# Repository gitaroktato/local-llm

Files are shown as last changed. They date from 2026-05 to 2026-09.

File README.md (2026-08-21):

# Local LLM 
A combination of hardware and software capable of running LLMs for coding locally. 

## Execution Environments

- [Arch Linux and Unsloth](./arch-linux-unsloth.md)
- [Windows WSL with vLLM](./windows-wsl-vllm.md)
- 
## Hardware

Full bill of materials (BOM), PCIe topology, riser cables and 3D-printed parts: [hardware-bom.md](./hardware-bom.md)

- CPU: Intel Core i5-14400F · MB: ASUS ROG MAXIMUS Z690 HERO
- GPU: 2× NVIDIA RTX 5060 Ti 16GB (Gen5 x16 + Gen5 x1 riser path)
- RAM: 32GB DDR5-5200 (Kingston FURY Beast) · PSU: ASUS ROG STRIX 1000G

## Images
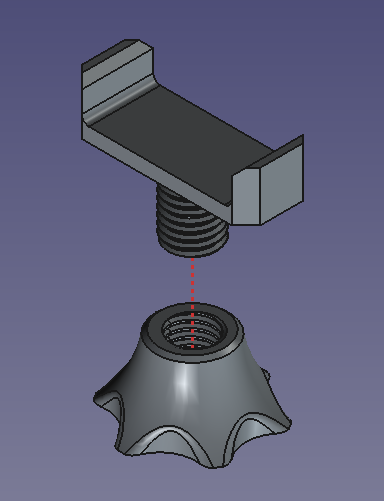
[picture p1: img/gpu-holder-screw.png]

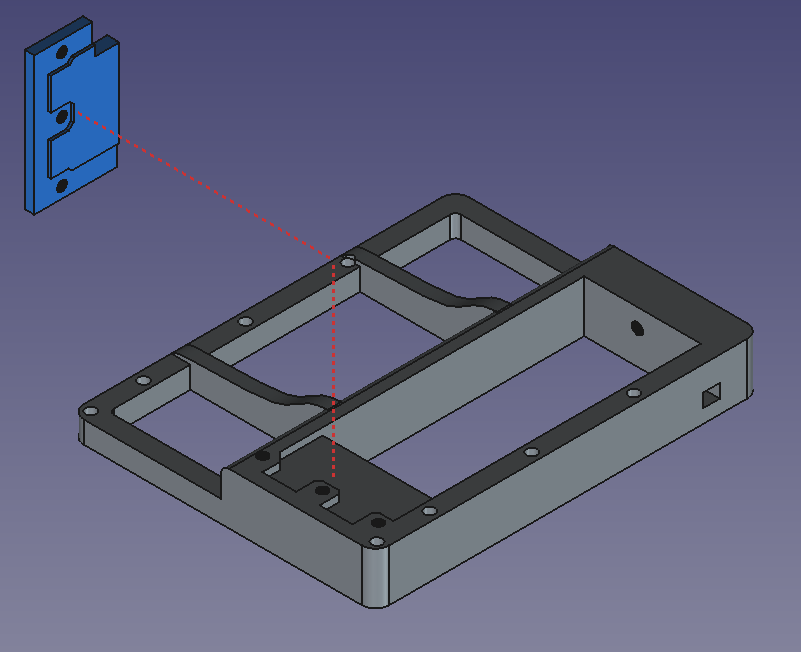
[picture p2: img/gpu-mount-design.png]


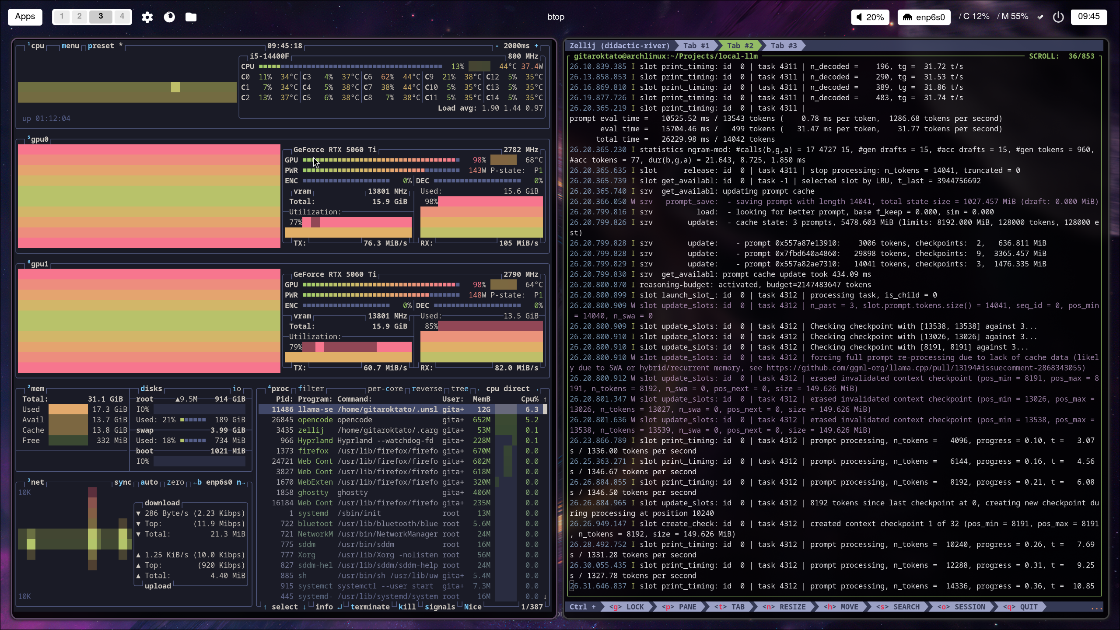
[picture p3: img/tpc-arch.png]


## Tools

Setting CPU governance

```bash
sudo cpupower frequency-set -g performance
```

- [GPU power cap ("undervolt")](./gpu-undervolt.md)

## References

- <https://zread.ai/abetlen/llama-cpp-python/20-kv-cache-strategies>
- <https://github.com/ggml-org/llama.cpp/discussions/14758>

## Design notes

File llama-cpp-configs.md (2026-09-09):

# llama-cpp Configs

Tip: Add `--metrics` for metrics

## Qwen 3.6 Q4_XL with 128k context window using Q5_1

```bash
llama-server -m /home/gitaroktato/.cache/huggingface/hub/models--unsloth--Qwen3.6-27B-GGUF/snapshots/82d411acf4a06cfb8d9b073a5211bf410bfc29bf/Qwen3.6-27B-UD-Q4_K_XL.gguf --port 35019 -c 128000 --parallel 1 --flash-attn on --no-context-shift -ngl -1 --threads -1 --jinja --cache-type-k q5_1 --cache-type-v q5_1 --spec-default --chat-template-kwargs {"enable_thinking": true} --mmproj /home/gitaroktato/.cache/huggingface/hub/models--unsloth--Qwen3.6-27B-GGUF/snapshots/82d411acf4a06cfb8d9b073a5211bf410bfc29bf/mmproj-F16.gguf
```

### Split-mode - tensor (simple run)

```bash
llama-server -m /home/gitaroktato/.cache/huggingface/hub/models--unsloth--Qwen3.6-27B-GGUF/snapshots/82d411acf4a06cfb8d9b073a5211bf410bfc29bf/Qwen3.6-27B-UD-Q4_K_XL.gguf --metrics --port 8888 -c 128000 --parallel 1 --flash-attn on --no-context-shift -ngl -1 --threads 16 --split-mode tensor --fit off --jinja --cache-type-k bf16 --cache-type-v bf16 --spec-default --chat-template-kwargs '{"enable_thinking": true}' --mmproj /home/gitaroktato/.cache/huggingface/hub/models--unsloth--Qwen3.6-27B-GGUF/snapshots/82d411acf4a06cfb8d9b073a5211bf410bfc29bf/mmproj-F16.gguf
```

## Qwen 3.6 35B-A3B Q4_XL with 128k context window

```bash
llama-server -m /home/gitaroktato/.cache/huggingface/hub/models--unsloth--Qwen3.6-35B-A3B-GGUF/snapshots/a483e9e6cbd595906af30beda3187c2663a1118c/Qwen3.6-35B-A3B-UD-Q4_K_XL.gguf --port 48713 -c 262144 --parallel 1 --flash-attn on --no-context-shift -ngl -1 --threads -1 --jinja --spec-default --chat-template-kwargs {"enable_thinking": false} --mmproj /home/gitaroktato/.cache/huggingface/hub/models--unsloth--Qwen3.6-35B-A3B-GGUF/snapshots/a483e9e6cbd595906af30beda3187c2663a1118c/mmproj-F16.gguf
```

### Split-mode - tensor (simple run)

```bash
llama-server -m /home/gitaroktato/.cache/huggingface/hub/models--unsloth--Qwen3.6-35B-A3B-GGUF/snapshots/a483e9e6cbd595906af30beda3187c2663a1118c/Qwen3.6-35B-A3B-UD-Q4_K_XL.gguf  --port 8888 -c 128000 --parallel 1 --flash-attn on --no-context-shift -ngl -1 --threads 16 --split-mode tensor --fit off --jinja --cache-type-k bf16 --cache-type-v bf16 --spec-default --chat-template-kwargs '{"enable_thinking": true}' --mmproj  /home/gitaroktato/.cache/huggingface/hub/models--unsloth--Qwen3.6-35B-A3B-GGUF/snapshots/a483e9e6cbd595906af30beda3187c2663a1118c/mmproj-F16.gguf
```

## Qwen 3.8 - split-mode tensor (simple run)

```bash
llama-server -m /home/gitaroktato/.cache/huggingface/hub/models--unsloth--Qwen3.8-27B-GGUF/snapshots/f1bfb127c64f7072bdd2cad55f258b9c8b2910fe/Qwen3.8-27B-UD-Q5_K_XL.gguf --port 8888 --parallel 4 --flash-attn on --no-context-shift -c 128000 --alias unsloth/Qwen3.8-27B-GGUF -ngl -1 --threads 16 --split-mode tensor --fit off --metrics --slot-save-path /home/gitaroktato/.unsloth/studio/cache/llama-slots --cache-type-k bf16 --cache-type-v bf16 --kv-unified --jinja --spec-type ngram-mod --spec-ngram-mod-n-match 24 --spec-ngram-mod-n-min 48 --spec-ngram-mod-n-max 64 --chat-template-kwargs '{"enable_thinking": true, "preserve_thinking": false, "reasoning_effort":"medium"}' --mmproj /home/gitaroktato/.cache/huggingface/hub/models--unsloth--Qwen3.8-27B-GGUF/snapshots/f1bfb127c64f7072bdd2cad55f258b9c8b2910fe/mmproj-F16.gguf
```

From `unsloth studio`

```bash
llama-server -m /home/gitaroktato/.cache/huggingface/hub/models--unsloth--Qwen3.8-27B-GGUF/snapshots/f1bfb127c64f7072bdd2cad55f258b9c8b2910fe/Qwen3.8-27B-UD-Q5_K_XL.gguf --port 37741 --parallel 1 --flash-attn on --no-context-shift -c 104448 --alias unsloth/Qwen3.8-27B-GGUF -ngl -1 --fit off --metrics --slot-save-path /home/gitaroktato/.unsloth/studio/cache/llama-slots --jinja --split-mode tensor --spec-type draft-mtp --spec-draft-n-max 2 --chat-template-kwargs {"enable_thinking": true, "preserve_thinking": true} --mmproj /home/gitaroktato/.cache/huggingface/hub/models--unsloth--Qwen3.8-27B-GGUF/blobs/cbb841a9ee0636b2ec172f5bb8df2ea8dfeb01e90fe7c6126581d662a0b4e43e
```

```bash
llama-server -m /home/gitaroktato/.cache/huggingface/hub/models--unsloth--Qwen3.8-27B-GGUF/snapshots/f1bfb127c64f7072bdd2cad55f258b9c8b2910fe/Qwen3.8-27B-UD-Q5_K_XL.gguf --port 43775 --parallel 1 --flash-attn on --no-context-shift -c 101632 --alias unsloth/Qwen3.8-27B-GGUF -ngl -1 --fit off --metrics --slot-save-path /home/gitaroktato/.unsloth/studio/cache/llama-slots --jinja --split-mode tensor --spec-type draft-mtp --spec-draft-n-max 2 --chat-template-kwargs {"enable_thinking": true, "preserve_thinking": true} --mmproj /home/gitaroktato/.cache/huggingface/hub/models--unsloth--Qwen3.8-27B-GGUF/blobs/cbb841a9ee0636b2ec172f5bb8df2ea8dfeb01e90fe7c6126581d662a0b4e43e --threads 16
```

Optimization run 3

```bash
llama-server -m /home/gitaroktato/.cache/huggingface/hub/models--unsloth--Qwen3.8-27B-GGUF/snapshots/f1bfb127c64f7072bdd2cad55f258b9c8b2910fe/Qwen3.8-27B-UD-Q5_K_XL.gguf --port 41207 --parallel 1 --flash-attn on --no-context-shift -c 79616 --ubatch-size 1024 --alias unsloth/Qwen3.8-27B-GGUF -ngl -1 --fit off --metrics --slot-save-path /home/gitaroktato/.unsloth/studio/cache/llama-slots --jinja --split-mode tensor --spec-type draft-mtp --spec-draft-n-max 2 --chat-template-kwargs {"enable_thinking": true, "preserve_thinking": true} --mmproj /home/gitaroktato/.cache/huggingface/hub/models--unsloth--Qwen3.8-27B-GGUF/blobs/cbb841a9ee0636b2ec172f5bb8df2ea8dfeb01e90fe7c6126581d662a0b4e43e --threads 10
```

Optimization run 4 (vision on CPU) - not good, eats a lot of CPU

```bash
llama-server -m /home/gitaroktato/.cache/huggingface/hub/models--unsloth--Qwen3.8-27B-GGUF/snapshots/f1bfb127c64f7072bdd2cad55f258b9c8b2910fe/Qwen3.8-27B-UD-Q5_K_XL.gguf --port 48705 --parallel 1 --flash-attn on --no-context-shift -c 128000 --ubatch-size 1024 --alias unsloth/Qwen3.8-27B-GGUF --fit on --metrics --slot-save-path /home/gitaroktato/.unsloth/studio/cache/llama-slots --fit-ctx 128000 --fit-target 547 --jinja --spec-type none --chat-template-kwargs {"enable_thinking": true, "preserve_thinking": true} --mmproj /home/gitaroktato/.cache/huggingface/hub/models--unsloth--Qwen3.8-27B-GGUF/blobs/cbb841a9ee0636b2ec172f5bb8df2ea8dfeb01e90fe7c6126581d662a0b4e43e --threads 10 --split-mode layer --no-mmproj-offload
```

## Interesting things to try

- <https://www.reddit.com/r/LocalLLM/comments/1was9n0/running_qwen_38_27b_at_q4_on_16gb_vram_at_200k/>

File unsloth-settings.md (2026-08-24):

# Unsloth settings through UI

- KV cache: f16
- Speculative decoding: auto
- Parallel slots: 1
- Batch size: auto
- Micro-batch size: 1024
- Tensor parallelism: true
- Vision: true
- GPU memory: default
- VRAM budget: 98%
- GPUs: all on
- Chat Template: default
- Mmap / Mlock: auto
- Checkpoints: auto
- Cache RAM: auto

Additional args

```bash
--threads 10 --chat-template-file /home/gitaroktato/Projects/local-llm/chat-templates/qwen3.8-froggeric-v22.3.jinja --reasoning-format deepseek
```

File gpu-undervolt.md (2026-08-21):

# GPU Power Cap ("Undervolt")

On NVIDIA Linux there is no true mV undervolt — the closest equivalent is a **power-limit cap** via `nvidia-smi -pl`. This page documents why, how it was applied on this machine (2× RTX 5060 Ti, driver `610.57.04`), and how to keep it across reboots.

## Why not a real undervolt?

- NVIDIA has never exposed a voltage-offset API in NVML on Linux. Probing `libnvidia-ml.so` confirms: no voltage-related symbols exist.
- mV undervolting (MSI Afterburner / Rivatuner) is **Windows-only**.
- Clock locking (`nvidia-smi -lgc`) is deprecated for this Blackwell driver generation — P-state query APIs return `NOT_SUPPORTED`, and nvidia-smi marks Applications Clocks as "deprecated". Excluded from scope.

The power cap is a soft PMU constraint: fully reversible, zero hardware risk. For LLM inference (often memory-bandwidth-bound and rarely at TDP), dropping the limit typically costs only a few % of throughput while cutting heat, noise and wall power.

## Applying the cap

Allowed range per card on the RTX 5060 Ti: **150–180 W** (stock `180 W`).

```bash
# check current limits
nvidia-smi --query-gpu=index,power.limit,power.default_limit,power.min_limit,power.max_limit --format=csv

# apply 150 W to all GPUs (applies live, no restart needed; root required)
sudo nvidia-smi -pl 150

# verify
nvidia-smi --query-gpu=index,power.limit --format=csv
```

Note: plain `-pl <watts>` already targets all GPUs. Do not use `--gpu-all` (not recognized) or `-i ALL` ("No devices found") on driver `610.x` — both fail. Setting the limit requires root; querying does not.

This machine runs at **150 W** on both GPUs. The cap was chosen directly (no 180/165/150 W perf-loss table was recorded) — inference throughput was acceptable and heat/noise reduction was the goal.

## Persistence across reboots

The cap does not survive a driver reload or reboot by itself. Two pieces:

### 1. `nvidia-persistenced`

Keeps the driver loaded (and the daemon context alive) between sessions:

```bash
sudo systemctl enable --now nvidia-persistenced
```

### 2. Oneshot unit applying the cap at boot

`/etc/systemd/system/gpu-power-cap.service`:

```ini
[Unit]
Description=Apply 150 W power cap to all NVIDIA GPUs
After=sysinit.target nvidia-persistenced.service
ConditionPathExists=/usr/bin/nvidia-smi

[Service]
Type=oneshot
RemainAfterExit=yes
ExecStart=/bin/sh -c 'for i in $(seq 1 30); do nvidia-smi -pl 150 >/dev/null && exit 0; sleep 2; done; echo "gpu-power-cap: failed to apply power limit after retries" >&2; exit 1'

[Install]
WantedBy=multi-user.target
```

The retry loop (30 × 2 s) covers the case where the nvidia module is not up yet when the unit runs. Install and enable:

```bash
sudo cp gpu-power-cap.service /etc/systemd/system/
sudo systemctl daemon-reload
sudo systemctl enable --now gpu-power-cap.service
```

### Verify after reboot

```bash
nvidia-smi --query-gpu=index,power.limit --format=csv   # expect 150.00 W on both
systemctl status gpu-power-cap.service nvidia-persistenced.service
```

## Revert

```bash
sudo nvidia-smi -pl 180              # restore stock limit on all GPUs (live)
sudo systemctl disable --now gpu-power-cap.service   # optional: stop forcing the cap at boot
```

No clock locks, no register hacks — everything is reversible.

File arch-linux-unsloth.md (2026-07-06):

# Running through Unsloth + Arch Linux

## Commands

### PCIe testing

Getting PCIe lane bandwidth (possible):

```shell
sudo watch -c -n2 'lspci -s 00:01.0 -vvv | grep LnkSta'
```

Understanding actual bandwidth with `nvidia-smi`:

```shell
nvidia-smi dmon -s pceutv -d 1
```

Just RX/TX

```shell
nvidia-smi dmon -s t -d 1
```

### PCIe benchmarks

Stress-testing PCIe port
Should be possible with `gpu-burn-git`: <https://aur.archlinux.org/packages/gpu-burn-git>

### Using `nvbandwith`

See: https//github.com/NVIDIA/nvbandwidth

Make sure you have NVidia toolkit and `nvcc` installed.
Put the following lines into your `.bashrc`

```bash
export PATH=/opt/cuda/bin:$PATH
export LD_LIBRARY_PATH=/opt/cuda/lib64:$LD_LIBRARY_PATH
```

Add `boost-libs` with

```shell
sudo pacman -S boost boost-libs
```

Compile from source with

```bash
cmake .
make
```

Run benchmarks:

```bash
nvbandwidth -t host_to_device_bidirectional_memcpy_ce
nvbandwidth -t device_to_host_bidirectional_memcpy_ce
nvbandwidth -t host_to_device_bidirectional_memcpy_sm
nvbandwidth -t device_to_host_bidirectional_memcpy_sm
nvbandwidth -p device_to_host_bidirectional -i 16
nvbandwidth -p host_to_device_bidirectional -i 16
```

Reference numbers:

| PCIe generation | Signaling rate (GT/s per lane) | Encoding | Effective per-lane throughput (GB/s) | Effective x4 link, one-way (GB/s) | Effective x8 link, one-way (GB/s) |
|---|---:|---|---:|---:|---:|
| PCIe 3.0 | 8.0 | 128b/130b | 0.985 | 3.94 | 7.88 |
| PCIe 4.0 | 16.0 | 128b/130b | 1.969 | 7.88 | 15.75 |
| PCIe 5.0 | 32.0 | 128b/130b | 3.938 | 15.75 | 31.51 |

Notes:

- Values are unidirectional (one-way) effective line rates accounting for 128b/130b encoding overhead only. Additional PCIe protocol overhead further reduces payload throughput.
- PCIe links are full-duplex; the reverse direction has the same capacity.

## Target Hardware

- OS: Arch Linux
- GPU: RTX 5060 Ti 16GB
- Runtime: Unsloth + llama.cpp

## Possible Performance Bottlenecks

<!-- TODO local model bottlenecks VRAM throughput?? -->

## Optimizations per Task

### Qwen3.6-35B-A3B-GGUF

<!-- TODO local model optimizations and correct settings -->

<https://unsloth.ai/docs/models/qwen3.6#turn-on-off-thinking--preserve-thinking>

## Configuration and Optimization Tips

### 🧠 Memory & Quantization

- **Quantize model weights** — Reduce 16-bit weights to 8-bit or 4-bit using Unsloth's GGUF export
  to cut VRAM usage. The performance drop from 16→8 bit is far smaller than from 8→4 bit, so prefer
  Q8 where VRAM allows and fall back to Q4 when needed.
- **Prefer larger models with aggressive quantization over smaller precise ones** — A Q4 30B model
  generally outperforms a full-precision 7B model for coding tasks.
- **Be cautious with KV cache quantization** — `llama.cpp` supports KV cache quantization via
  `-ctk` / `-ctv` flags (e.g., `q8_0`). This is considered *more destructive* than weight
  quantization because it causes the model to lose detail in long reasoning traces. Benchmark your
  specific task before enabling it.
- **Prioritize a precise KV cache for coding/reasoning** — For agentic coding sessions where long
  context matters, keep KV cache at `f16` or `q8_0` and instead shrink the model size to fit VRAM.
  See related paper: <https://arxiv.org/pdf/2510.10964>
- **Monitor actual VRAM usage** — Use `nvidia-smi` (NVIDIA) or `rocm-smi` (AMD) to confirm the
  model fits in VRAM. Spilling into system RAM via llama.cpp's `-ngl` GPU offloading will
  drastically reduce tokens/second.

### 🏗️ Model Architecture & Selection

- **Prefer Hybrid Attention architectures** — Models like Qwen3 with Hybrid Attention have a
  significantly smaller KV cache footprint, letting you run a larger model within the same VRAM
  budget.
- **Use Instruct models for chat-based coding tools** — Use instruct-tuned variants (e.g.,
  `Qwen3-Coder-*-Instruct`) with tools like OpenCode or Continue. Use base models only for
  fill-in-the-middle (FIM) autocomplete.

### ⚡ llama.cpp Runtime Tuning

- **Maximize GPU layer offloading** — Pass `-ngl 99` (or the maximum layer count of your model) to
  offload all layers to the GPU. Partial offloading (`-ngl <n>`) is a valid fallback when VRAM is
  tight, at the cost of speed.
- **Set an appropriate context size** — Use `-c 65536` or larger for coding sessions. Prefer models
  with Hybrid Attention to keep the KV cache cost of a large context manageable.
- **Tune batch and thread counts** — Use `-b 512` or `-b 1024` to balance prompt processing
  throughput. Set `-t` to the number of physical CPU cores for CPU-assisted layers.
- **Watch time-to-first-token and tokens/second** — Both matter for interactive coding. If
  tokens/second is too low, reduce context size, increase quantization, or reduce `-ngl` to leave
  more VRAM headroom for the KV cache.

### 📐 Model Size Reference (VRAM Requirements — GGUF Q4)

| Model | Approx. VRAM |
|---|---|
| Qwen3-4B-Instruct Q4 | ~3 GB |
| Qwen2.5-14B-Instruct Q4 | ~9 GB |
| Qwen3-Coder-30B-A3B-Instruct Q4 | ~18 GB |
| Qwen3-Coder-30B-A3B-Instruct Q8 | ~33 GB |
| Qwen3-Next-80B-A3B-Instruct Q4 | ~48 GB |

Use the [VRAM calculator](https://apxml.com/tools/vram-calculator) for precise estimates including
KV cache overhead for your target context length.

### 📝 Usage & Workflow

- **Manage context deliberately** — Only include files and context directly relevant to the current
  task. Bloated context degrades performance and increases KV cache memory pressure.
- **Use OpenAI-compatible tools** — Tools that speak the OpenAI API standard (OpenCode, Continue,
  Aider, Roo Code) make it trivial to swap models without reconfiguring the tool.

## Bookmarks

### Hardware

- [PCIe Accelerator - Skymizer HTX301](https://wccftech.com/this-pcie-ai-accelerator-card-packs-384-gb-memory-run-700b-llms-240w/)
- [Blackhole PCIe](https://tenstorrent.com/hardware/cards)

### Embedded

- [RPi AI HAT +2](https://www.raspberrypi.com/documentation/accessories/ai-hat-plus.html#AIHAT-models)
- [RPi + M.2 via OCuLink](https://youtu.be/SPTYjF8qH0A)
- [RPi + M.2 via OCuLink #2](https://youtu.be/b58eok9TP9Y)
- [RPi + M.2 via OCuLink #3](https://youtu.be/jeuOMDfY-MI)
- [RPi + M.2 via OCuLink #4](https://youtu.be/AyR7iCS7gNI)

### Hardware Builds

- [Personal-AI-Computer](https://github.com/autonomous-ai/Personal-AI-Computer/tree/main)
- [Personal AI Computerhttps://github.com/autonomous-ai/Personal-AI-Computer/tree/main#bios-optimization-for-gpu-performance Blog](https://www.autonomous.ai/ourblog/how-to-build-your-own-personal-ai-computer)

### Benchmarks

- [Choosing right GPU for LLMs](https://www.llamabuilds.ai/blog/choosing-right-gpu-for-llms)
- [LLM Benchmarks](https://www.llamabuilds.ai/benchmarks)
- [swe-bench-verified](https://llm-stats.com/benchmarks/swe-bench-verified)
- [livecodebench](https://llm-stats.com/benchmarks/livecodebench)

### Tools

- [pi.dev](https://pi.dev/docs/latest)

### Useful Links

- [VRAM calculator](https://apxml.com/tools/vram-calculator)
- [Unsloth with OpenCode](https://unsloth.ai/docs/integrations/opencode)
- [Guide on local LLMs](https://www.reddit.com/r/LocalLLaMA/comments/1sknx6n/best_local_llms_apr_2026/)

### Blogposts

- [Local LLM introduction](https://www.aiforswes.com/p/you-dont-need-to-spend-100mo-on-claude)

### Benchmarking

- <https://openbenchmarking.org/>

### Papers

- [Context window VS model quantization](https://arxiv.org/pdf/2510.10964)
- [Qwen3 training and inference optimizations](https://qwen.ai/blog?id=4074cca80393150c248e508aa62983f9cb7d27cd&from=research.latest-advancements-list)

### Qwen model configs

- <https://docsmith.aigne.io/docs/qwen-agent/en/reference-models-d8daab#example%3A-efficient-configuration>

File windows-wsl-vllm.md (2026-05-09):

# Local LLM with vLLM

## Installing CUDA drivers on WSL 

### Installing CUDA drivers

```shell
wget https://developer.download.nvidia.com/compute/cuda/repos/wsl-ubuntu/x86_64/cuda-keyring_1.1-1_all.deb
sudo dpkg -i cuda-keyring_1.1-1_all.deb
sudo apt-get update
sudo apt-get -y install cuda-toolkit-13-1
```

### Verifying CUDA drivers

Verify CUDA version on the right side.

```shell
nvidia-smi
```

### Install Docker

Download and install docker

```shell
curl https://get.docker.com | sh
sudo service docker start
```

Allow docker for non-root users as well

```shell
sudo groupadd docker
sudo usermod -aG docker $USER
newgrp docker
```

### Install CUDA Container Toolkit

Install the prerequisites for the instructions below
```shell
sudo apt-get update && sudo apt-get install -y --no-install-recommends \
   curl \
   gnupg2
```

Configure the production repository

```shell
curl -fsSL https://nvidia.github.io/libnvidia-container/gpgkey | sudo gpg --dearmor -o /usr/share/keyrings/nvidia-container-toolkit-keyring.gpg \
  && curl -s -L https://nvidia.github.io/libnvidia-container/stable/deb/nvidia-container-toolkit.list | \
    sed 's#deb https://#deb [signed-by=/usr/share/keyrings/nvidia-container-toolkit-keyring.gpg] https://#g' | \
    sudo tee /etc/apt/sources.list.d/nvidia-container-toolkit.list
```

Update the packages list from the repository
```shell
sudo apt-get update

export NVIDIA_CONTAINER_TOOLKIT_VERSION=1.18.1-1
  sudo apt-get install -y \
      nvidia-container-toolkit=${NVIDIA_CONTAINER_TOOLKIT_VERSION} \
      nvidia-container-toolkit-base=${NVIDIA_CONTAINER_TOOLKIT_VERSION} \
      libnvidia-container-tools=${NVIDIA_CONTAINER_TOOLKIT_VERSION} \
      libnvidia-container1=${NVIDIA_CONTAINER_TOOLKIT_VERSION}
```

### Configure CUDA Container Toolkit

```shell
nvidia-ctk runtime configure --runtime=docker
sudo service docker restart
```

### Verify CUDA Container Toolkit

```shell
sudo docker run --rm --runtime=nvidia --gpus all ubuntu nvidia-smi
```

```shell
sudo docker run --gpus all nvcr.io/nvidia/k8s/cuda-sample:nbody nbody -gpu -benchmark
```

### Run vLLM 25.12
Check for compatibility with CUDA toolkit first. For instance vLLM 25.12 is compatible with CUDA toolkit 13.1.

```bash
docker run --gpus all -it --rm nvcr.io/nvidia/vllm:25.12-py3
```

### Issues with vLLM and WSL 2

Possible issue on lower peformance, when running through WSL 2 - [issue ticket](https://github.com/vllm-project/vllm/issues/1084)

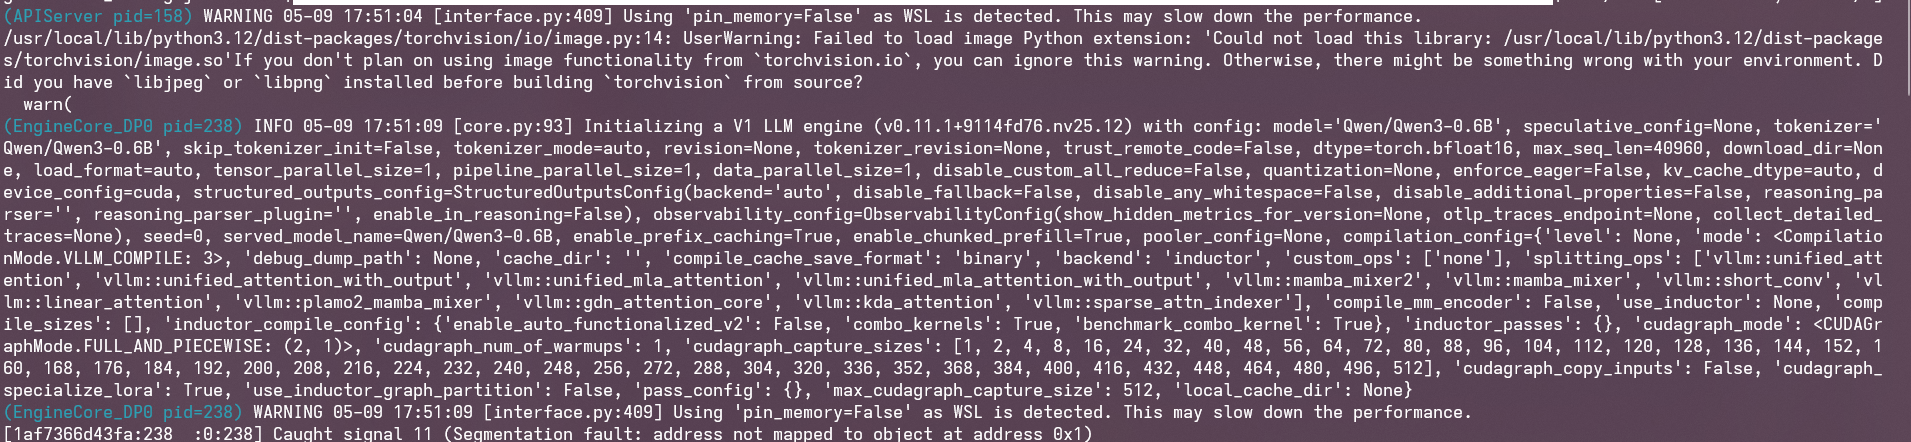
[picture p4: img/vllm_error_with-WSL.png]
vLLM error with WSL
Example from local run: 

### Reference Pages

#### CUDA drivers

- https://learn.microsoft.com/en-us/windows/ai/directml/gpu-cuda-in-wsl
- https://docs.nvidia.com/cuda/wsl-user-guide/index.html#getting-started-with-cuda-on-wsl
- https://developer.nvidia.com/cuda-downloads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
- https://docs.nvidia.com/cuda/cuda-installation-guide-linux/index.html#meta-packages

#### NVIDIA Container Toolkit

- https://docs.nvidia.com/datacenter/cloud-native/container-toolkit/latest/install-guide.html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
- https://docs.nvidia.com/datacenter/cloud-native/container-toolkit/latest/install-guide.html#configuration

#### vLLM

- https://docs.vllm.ai/en/stable/getting_started/installation/gpu/#pre-built-wheels
- https://docs.nvidia.com/deeplearning/frameworks/vllm-release-notes/rel-25-12.html

#### Docker
- https://docs.docker.com/engine/install/ubuntu/#install-using-the-repository
- https://learn.microsoft.com/en-us/windows/wsl/tutorials/gpu-compute
- https://docs.docker.com/engine/install/linux-postinstall/

#### Open WebUI
- https://github.com/open-webui/open-webui

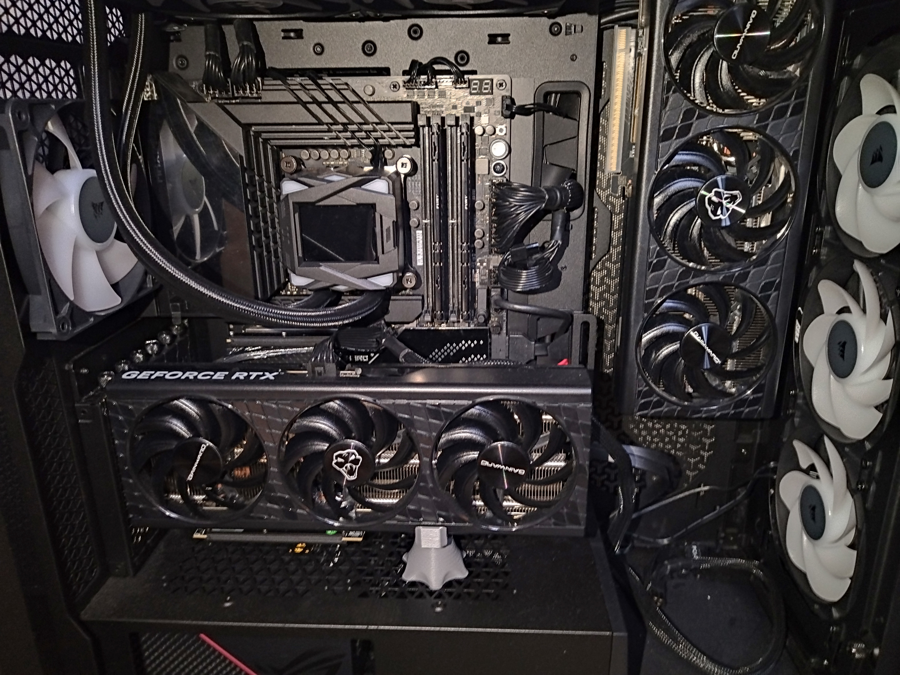
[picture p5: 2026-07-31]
img/hardware-offline.jpg

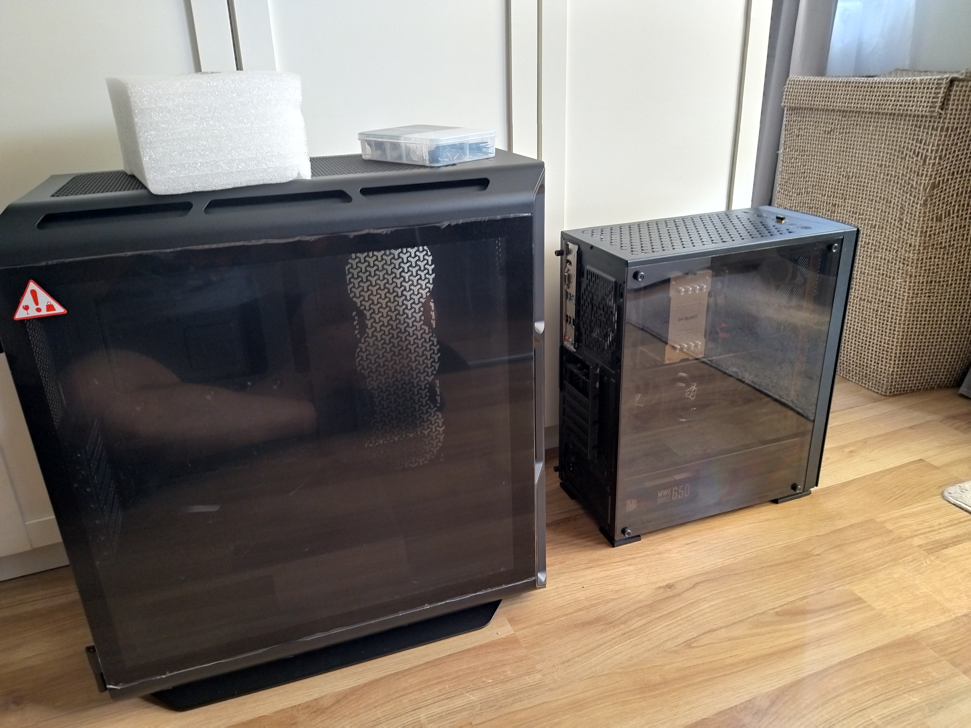
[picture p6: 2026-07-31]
img/case-change.jpg

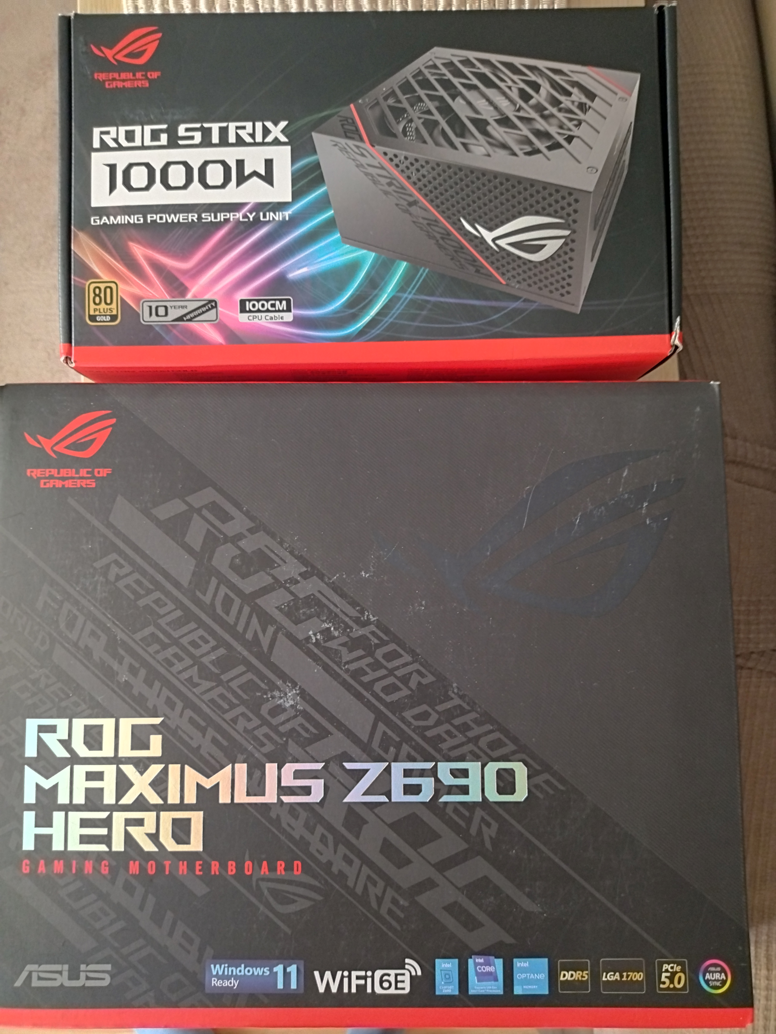
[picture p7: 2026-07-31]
img/motherboard-part.jpg

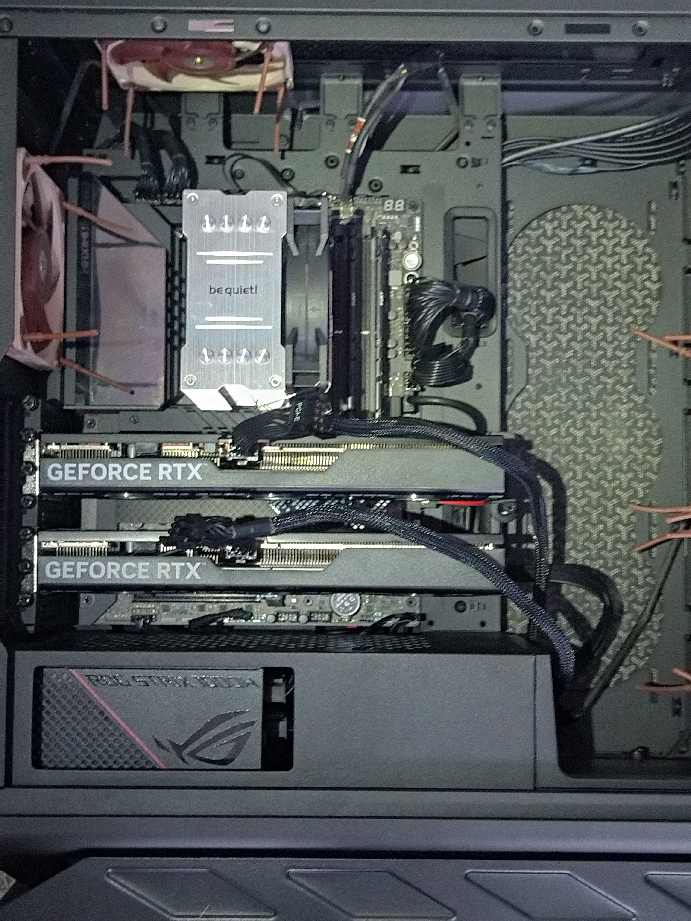
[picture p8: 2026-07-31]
img/dual-gpu-no-thermal.jpg

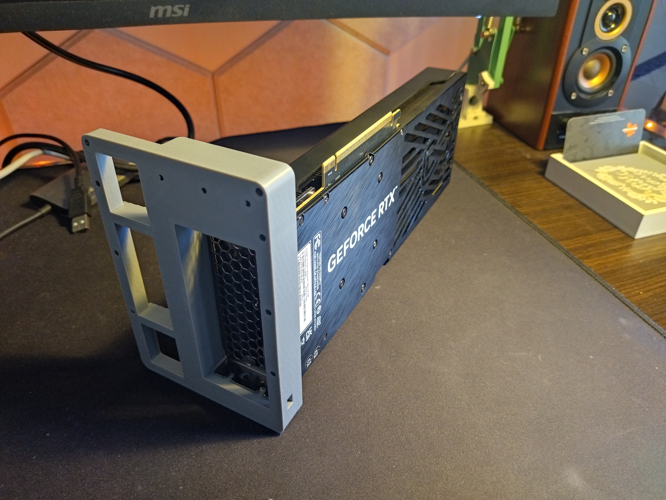
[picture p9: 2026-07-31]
img/gpu-mount-short-2.jpg

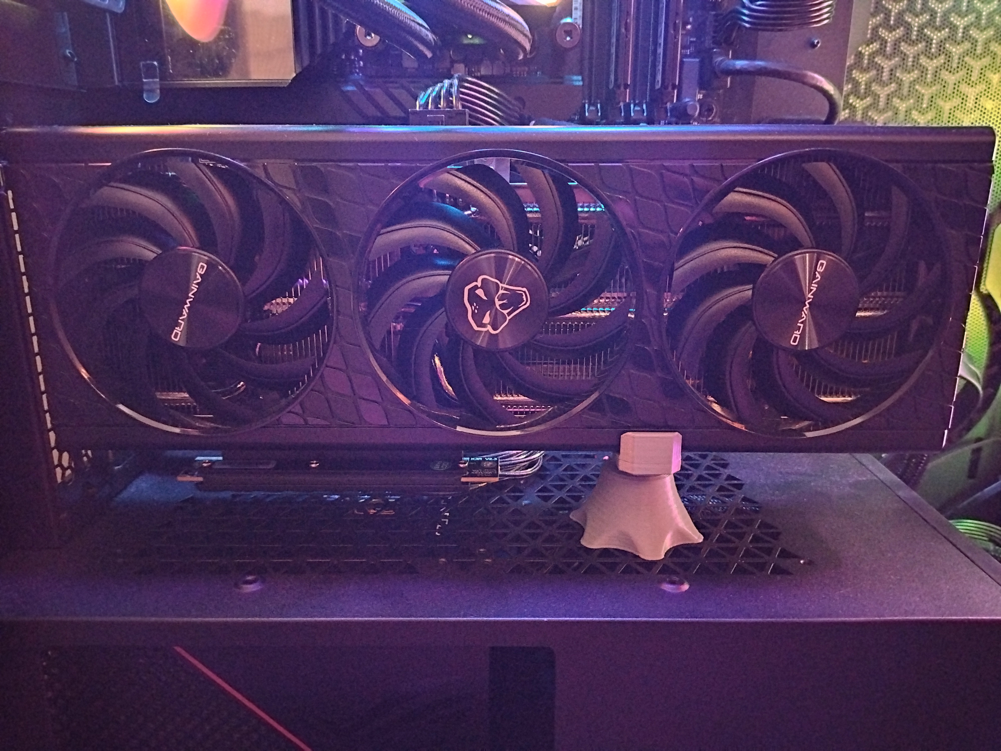
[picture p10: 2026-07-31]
img/gpu-screw.jpg

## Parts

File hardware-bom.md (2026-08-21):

# Hardware BOM

Bill of materials for the local LLM build machine (identified in issue #8).

## Bill of Materials

| Component | Part / Model | Qty | Notes | Reference |
|---|---|-----|---|---|
| CPU | Intel Core i5-14400F | 1 | 10C/16T, up to 4.7 GHz | [Intel ARK](https://ark.intel.com/content/www/us/en/ark/products/236181/intel-core-i5-1440f-processor-20m-cache.html) |
| Motherboard | ASUS ROG MAXIMUS Z690 HERO | 1 | Intel Z690, ATX | [ASUS product page](https://rog.asus.com/us/motherboards/rog-maximus/rog-maximus-z690-hero-model/spec/) |
| GPU | NVIDIA GeForce RTX 5060 Ti 16GB (GB206) | 2 | Driver 610.57.04 | [NVIDIA](https://www.nvidia.com/en-us/geforce/graphics-cards/50-series/rtx-5060-ti/) · [TechPowerUp specs](https://www.techpowerup.com/gpu-specs/rtx-5060-ti-16gb.c4273) |
| RAM | Kingston FURY Beast KF552C36BBEK2-32 (2×16GB DDR5-5200 CL36) | 1 kit (2 DIMMs) | ~32GB total | [Kingston datasheet](https://www.kingston.com/datasheets/KF552C36BWEAK2-32.pdf) |
| PSU | ASUS ROG STRIX 1000G (1000W) | 1 | | [ASUS product page](https://rog.asus.com/power-supply-units/rog-strix/rog-strix-1000g-model/) |
| Case | Corsair 5000T Black (CC-9011300-ww) | 1 | Mid tower, high performance; see `img/case-change.jpg` | [Corsair product page](https://www.corsair.com/us/en/p/pc-cases/cc-9011300-ww/5000t-mid-tower-high-performance-pc-case-cc-9011300-ww) |
| OS | Arch Linux | — | See [arch-linux-unsloth.md](./arch-linux-unsloth.md) | |

## PCIe Riser Cables

Both GPUs are mounted off-slot via ADT-LINK (Ares) PCIe 5.0 riser cables:

| Riser | Length | Notes |
|---|---|---|
| ADT-LINK K33UR-TL | 30 cm | PCIe 5.0 x16 → x16, full speed (512 GB/s max) |
| ADT-LINK K33UF-TR | 60 cm | PCIe 5.0 x16 → x16, full speed (512 GB/s max) |

Reference: [ADT-LINK K33Ux-T product page](https://www.adtlink.com/product/K33Ux-T.html) · [adt.link x16 overview](https://www.adt.link/x16.html)

## PCIe Topology

- **GPU0** — Gen5 x16, wired to the CPU root port (`00:01.0`). Full width from the socket.
- **GPU1** — Gen5 **x1**, via the riser path on root port `00:01.1`. Bandwidth is capped at x1 (~4 GB/s); NVLink-style P2P across the pair is not possible, so multi-GPU inference should rely on tensor/pipe parallelism over PCIe or fit the model on one GPU when practical.

## 3D-Printed Parts

Custom parts for mounting the second GPU and holding cabling; CAD sources (FreeCAD) included:

| Part | STL | Source | Preview |
|---|-----|---|---|
| GPU holder base | `designs/GPU-holder-base.stl` | `designs/GPU-holder.FCStd` | [img/gpu-holder-screw.png](img/gpu-holder-screw.png) |
| GPU holder screw body | `designs/GPU-holder-screw-body.stl` | `designs/GPU-holder.FCStd` | [img/gpu-screw.jpg](img/gpu-screw.jpg) |
| GPU mount | `designs/GPU_mount-gpumount.stl` | `designs/GPU_mount.FCStd` | [img/gpu-mount-design.png](img/gpu-mount-design.png) |
| GPU mount lock | `designs/GPU_mount-lock.stl` | `designs/GPU_mount.FCStd` | [img/gpu-mount.jpg](img/gpu-mount.jpg) |

## Photos

| Photo | Description |
|---|---|
| [final-machine.jpg](img/final-machine.jpg) | Finished build |
| [dual-gpu-no-thermal.jpg](img/dual-gpu-no-thermal.jpg) | Dual GPU before thermal paste |
| [gpu-mount-vertical.jpg](img/gpu-mount-vertical.jpg) | Vertical GPU mount |
| [motherboard-part.jpg](img/motherboard-part.jpg) | Motherboard / riser wiring |
| [pcie5-flex.jpg](img/pcie5-flex.jpg) · [pcie-flex2.jpg](img/pcie-flex2.jpg) | PCIe 5.0 flex risers |
| [gpu-mount-short-1.jpg](img/gpu-mount-short-1.jpg) · [gpu-mount-short-2.jpg](img/gpu-mount-short-2.jpg) · [gpu-mount-screw.jpg](img/gpu-mount-screw.jpg) | Mount assembly variants |
| [hardware-offline.jpg](img/hardware-offline.jpg) · [hardware-offline-2.jpg](img/hardware-offline-2.jpg) | Offline hardware shots |

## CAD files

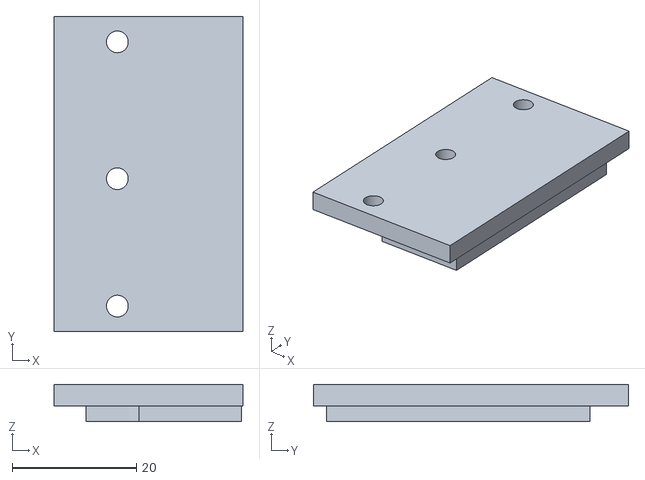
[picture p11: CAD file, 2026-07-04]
designs/GPU_mount-lock.stl
30.3 x 50.6 x 6.00

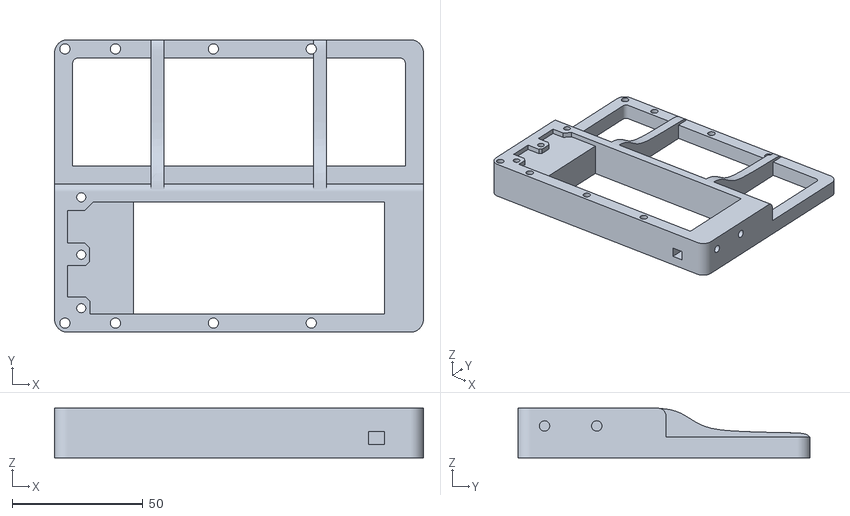
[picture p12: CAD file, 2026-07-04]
designs/GPU_mount-gpumount.stl
141.4 x 112.0 x 19.0

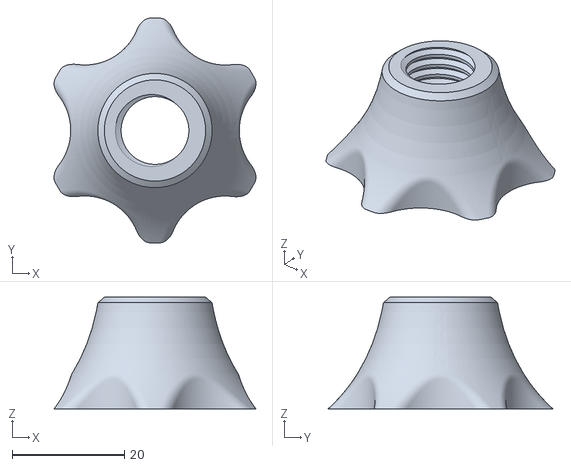
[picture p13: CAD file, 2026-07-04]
designs/GPU-holder-base.stl
35.9 x 40.0 x 19.9

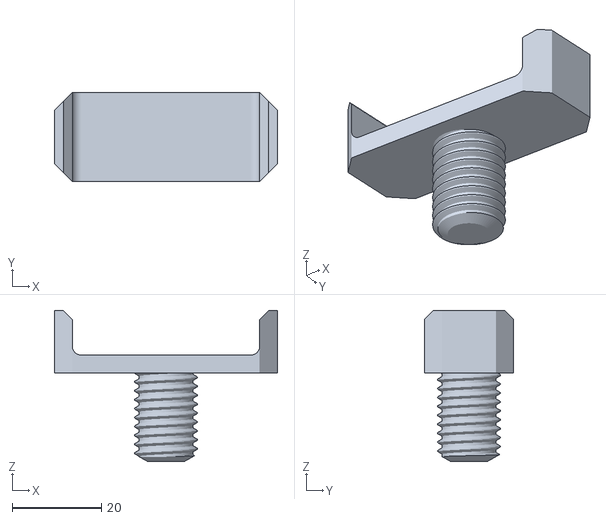
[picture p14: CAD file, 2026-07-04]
designs/GPU-holder-screw-body.stl
50.0 x 20.0 x 33.9

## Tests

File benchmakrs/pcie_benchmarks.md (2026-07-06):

# PCIe Benchmarks

## Diagnostics

```bash
sudo lspci -vvv | grep -E "LnkCap:|LnkSta:" | grep 'Port #0'
```

LnkCap (Capability): Should show `Speed 32GT/s` (which denotes PCIe 5.0).

LnkSta (Current Status): Should also show `Speed 32GT/s`. If `LnkSta` shows `16GT/s` (PCIe 4.0) or `8GT/s` (PCIe 3.0) while the GPU is under load, the riser cable is degrading the signal.

```bash
sudo dmesg | grep -i -E "pcie|aer"
```

What to look for: If you see a stream of `PCIe Bus Error: severity=Corrected` or `Uncorrected` errors pointing to your GPU's PCI address, the riser cable is failing to provide adequate signal integrity for PCIe 5.0.

## Kolink 300mm PGW-RC-MRK-011 

```bash
nvbandwidth -p host_to_device_bidirectional -i 128
```

```text
nvbandwidth Version: v0.9
Built from Git version: v0.9

CUDA Runtime Version: 13030
CUDA Driver Version: 13030
Driver Version: 610.43.02

archlinux
Device 0: NVIDIA GeForce RTX 5060 Ti (00000000:01:00)

Running host_to_device_bidirectional_memcpy_ce.
memcpy CE CPU(row) <-> GPU(column) bandwidth (GB/s)
           0
 0     18.00

SUM host_to_device_bidirectional_memcpy_ce 18.00

Running host_to_device_bidirectional_memcpy_sm.
memcpy SM CPU(row) <-> GPU(column) bandwidth (GB/s)
           0
 0     21.99

SUM host_to_device_bidirectional_memcpy_sm 21.99

NOTE: The reported results may not reflect the full capabilities of the platform.
Performance can vary with software drivers, hardware clocks, and system topology.
```

```bash
nvbandwidth -p device_to_host_bidirectional -i 128
```

```text
nvbandwidth Version: v0.9
Built from Git version: v0.9

CUDA Runtime Version: 13030
CUDA Driver Version: 13030
Driver Version: 610.43.02

archlinux
Device 0: NVIDIA GeForce RTX 5060 Ti (00000000:01:00)

Running device_to_host_bidirectional_memcpy_ce.
memcpy CE CPU(row) <-> GPU(column) bandwidth (GB/s)
           0
 0     26.78

SUM device_to_host_bidirectional_memcpy_ce 26.78

Running device_to_host_bidirectional_memcpy_sm.
memcpy SM CPU(row) <-> GPU(column) bandwidth (GB/s)
           0
 0     22.02

SUM device_to_host_bidirectional_memcpy_sm 22.02

NOTE: The reported results may not reflect the full capabilities of the platform.
Performance can vary with software drivers, hardware clocks, and system topology.
```

## ADT-LINK K33UR-TL 30 cm

```bash
nvbandwidth -p host_to_device_bidirectional -i 128
```

```text
nvbandwidth Version: v0.9
Built from Git version: v0.9

CUDA Runtime Version: 13030
CUDA Driver Version: 13030
Driver Version: 610.43.02

archlinux
Device 0: NVIDIA GeForce RTX 5060 Ti (00000000:01:00)

Running host_to_device_bidirectional_memcpy_ce.
memcpy CE CPU(row) <-> GPU(column) bandwidth (GB/s)
           0
 0     18.04

SUM host_to_device_bidirectional_memcpy_ce 18.04

Running host_to_device_bidirectional_memcpy_sm.
memcpy SM CPU(row) <-> GPU(column) bandwidth (GB/s)
           0
 0     22.43

SUM host_to_device_bidirectional_memcpy_sm 22.43

NOTE: The reported results may not reflect the full capabilities of the platform.
Performance can vary with software drivers, hardware clocks, and system topology.
```

```bash
nvbandwidth -p device_to_host_bidirectional -i 128
```

```text
nvbandwidth Version: v0.9
Built from Git version: v0.9

CUDA Runtime Version: 13030
CUDA Driver Version: 13030
Driver Version: 610.43.02

archlinux
Device 0: NVIDIA GeForce RTX 5060 Ti (00000000:01:00)

Running device_to_host_bidirectional_memcpy_ce.
memcpy CE CPU(row) <-> GPU(column) bandwidth (GB/s)
0
0     26.84

SUM device_to_host_bidirectional_memcpy_ce 26.84

Running device_to_host_bidirectional_memcpy_sm.
memcpy SM CPU(row) <-> GPU(column) bandwidth (GB/s)
0
0     22.49

SUM device_to_host_bidirectional_memcpy_sm 22.49

NOTE: The reported results may not reflect the full capabilities of the platform.
Performance can vary with software drivers, hardware clocks, and system topology.
```

## ADT-LINK K33UR-TL 30 cm and ADT-LINK K33UF-TR 60 cm

```bash
nvbandwidth -p host_to_device_bidirectional -i 128
```

```text
nvbandwidth Version: v0.9
Built from Git version: v0.9

CUDA Runtime Version: 13030
CUDA Driver Version: 13030
Driver Version: 610.43.02

archlinux
Device 0: NVIDIA GeForce RTX 5060 Ti (00000000:01:00)
Device 1: NVIDIA GeForce RTX 5060 Ti (00000000:02:00)

Running host_to_device_bidirectional_memcpy_ce.
memcpy CE CPU(row) <-> GPU(column) bandwidth (GB/s)
           0         1
 0     18.02     17.98

SUM host_to_device_bidirectional_memcpy_ce 36.00
COEFFICIENT_OF_VARIATION host_to_device_bidirectional_memcpy_ce 0.00

Running host_to_device_bidirectional_memcpy_sm.
memcpy SM CPU(row) <-> GPU(column) bandwidth (GB/s)
           0         1
 0     22.37     22.48

SUM host_to_device_bidirectional_memcpy_sm 44.85
COEFFICIENT_OF_VARIATION host_to_device_bidirectional_memcpy_sm 0.00

NOTE: The reported results may not reflect the full capabilities of the platform.
Performance can vary with software drivers, hardware clocks, and system topology.
```

```bash
nvbandwidth -p device_to_host_bidirectional -i 128
```

```text
nvbandwidth Version: v0.9
Built from Git version: v0.9

CUDA Runtime Version: 13030
CUDA Driver Version: 13030
Driver Version: 610.43.02

archlinux
Device 0: NVIDIA GeForce RTX 5060 Ti (00000000:01:00)
Device 1: NVIDIA GeForce RTX 5060 Ti (00000000:02:00)

Running device_to_host_bidirectional_memcpy_ce.
memcpy CE CPU(row) <-> GPU(column) bandwidth (GB/s)
           0         1
 0     26.83     26.83

SUM device_to_host_bidirectional_memcpy_ce 53.67
COEFFICIENT_OF_VARIATION device_to_host_bidirectional_memcpy_ce 0.00

Running device_to_host_bidirectional_memcpy_sm.
memcpy SM CPU(row) <-> GPU(column) bandwidth (GB/s)
           0         1
 0     22.48     22.49

SUM device_to_host_bidirectional_memcpy_sm 44.97
COEFFICIENT_OF_VARIATION device_to_host_bidirectional_memcpy_sm 0.00

NOTE: The reported results may not reflect the full capabilities of the platform.
Performance can vary with software drivers, hardware clocks, and system topology.
```

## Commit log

2026-06-30 feat: Adding design files
    [GPU-holder-base.stl, GPU-holder-screw-body.stl, GPU_mount-gpumount.stl]
2026-07-04 feat: Adding models
    [GPU_mount-lock.stl]
2026-08-21 docs: Add hardware BOM with reference sheets, risers, 3D parts, PCIe topology
    Closes #8
2026-08-21 docs: BOM - Kingston datasheet link, Corsair 5000T case, drop cooler/storage (#8)
2026-08-21 docs: GPU power cap ("undervolt") guide with persistence (#21)
